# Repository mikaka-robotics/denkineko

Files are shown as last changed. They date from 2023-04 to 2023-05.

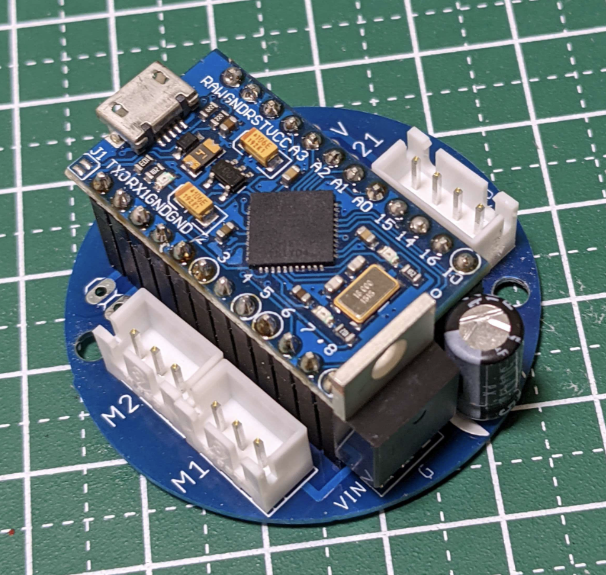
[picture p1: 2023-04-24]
circuit/circuit.png

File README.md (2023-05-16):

# 電気ネコ

- Demo動画<br>
demo (https://www.youtube.com/watch?v=TgMYkIjSbwk)

### デモの実行方法
事前に[こちらのNotebook](https://colab.research.google.com/drive/1hb-0-26DFwklIStM_WgTVe1c2eLKU9Zp?usp=sharing)でGradio web appを起動して、URL(https://XXXXXXXX.gradio.live/) をコピーしておく

```
git clone https://github.com/mikaka-robotics/denkineko.git
cd denkineko
(Macの場合) brew install portaudio
pip install -r  requirements.txt

python app.py --gradio_url https://XXXXXXXX.gradio.live/
```

起動後、[デモ動画](https://www.youtube.com/watch?v=TgMYkIjSbwk)のように頭のネジに触ることで会話を始められます。  

また、gradio_urlを与えずに`python app.py`のみで起動し、コマンドラインに直接コマンドを打ち込んでロボットを動かしてみることもできます。(送れるコマンドの詳細は以下)

# 開発者向け

スクリーンショット 2023-05-16 6 19 48

## ロボットとの通信方法の詳細
ロボットとの通信は、USBシリアル通信によって行っています。通信速度は9600bpsです。

- pythonなら以下のように命令を送れます. 

```python
import serial
import serial.tools.list_ports

com_ports = list(serial.tools.list_ports.comports())
#Arduinoが繋がっているportを調べて接続する
for port in com_ports:
    if "Arduino" in port.description:
        print("connect to " + port.device)     
        ser = serial.Serial(port.device, 9600, timeout=0.10)
        break

ser.write("nod,rainbow".encode())
```

ロボットが受け付ける命令は以下です。

|  コマンド名 | 動作 | 
| --- | --- |
| nod | うなずく nodnodで２回うなずく | 
| shake_body | 体を左右に揺らす | 
| neck数字 | 数字の角度に首を縦に動かす  例: neck80<br>範囲は (下向き  65 ~  90 上向き) | 
| body数字 | 数字の角度に体を横に動かす 例: body120<br>範囲は (右  0 ~  180 左) | 
| home | 首と体をホームポジションに戻す | 
| ready | LEDを通常状態にする | 
| rainbow | LEDを虹色にする | 
| lipsync | LEDをランダムに明滅させる | 
| sleep | スリープモードにする(ロボットが寝ます) | 
| blue | LEDを青にする | 
| yellow | LEDを黄色にする | 
| red | LEDを赤にする | 
| orange | LEDをオレンジにする | 
| white | LEDを白にする | 
| bright数字 | LEDの明るさを調整する (0~255)<br>例: bright50 | 
| status | 現在のロボットの状態を送信させる<br>[sleep/ready] | 

- 逆に、ロボット頭のネジがタッチされた場合は、`touch`という文字列がロボットから送られてきます。
- 命令はカンマ区切りで同時に複数送れます (ex `nod,rainbow`)

## ロボットのプログラムについて
- 使っているマイコンは[Arduino Leonardo](www.amazon.co.jp/dp/B07C31L2B6)です。  
  [こちら](https://github.com/mikaka-robotics/denkineko/blob/main/arduino_sketch/denkineko.ino)に書き込んでいるスケッチを置いています。

## 部品について
使用している主な部品は以下です。  

|  部品 | 数 | 型番など | 
| --- | --- | --- |
| サーボモータ | 2 | www.amazon.co.jp/dp/B09V4PZFCM  | 
| Arduino | 1 | www.amazon.co.jp/dp/B07C31L2B6 | 
| RGB LED | 1 | https://akizukidenshi.com/catalog/g/gI-08411/ | 
| 3.3V 3端子レギュレータ | 1 | https://akizukidenshi.com/catalog/g/gI-14505/| 

## 回路について
台座部分に回路が入っています。

スクリーンショット 2023-05-16 6 54 43

Eagleのプリント基板データがcircuitフォルダに入っています (部品名などめちゃくちゃ). 

スクリーンショット 2023-04-16 18 42 36. 




## 3Dプリントデータ
こちらのGoogle Driveにstlファイルがあります。  
https://drive.google.com/drive/folders/1kf-iSnG7YmpUBoflxnHEyxiMmFvtSxVS?usp=sharing. 
外装部分については光造形方式の3Dプリンタ必須です。

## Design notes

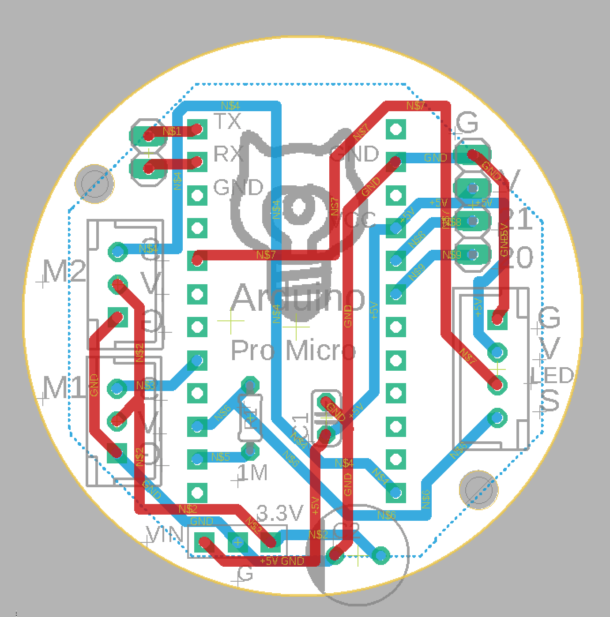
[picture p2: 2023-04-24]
circuit/board.png

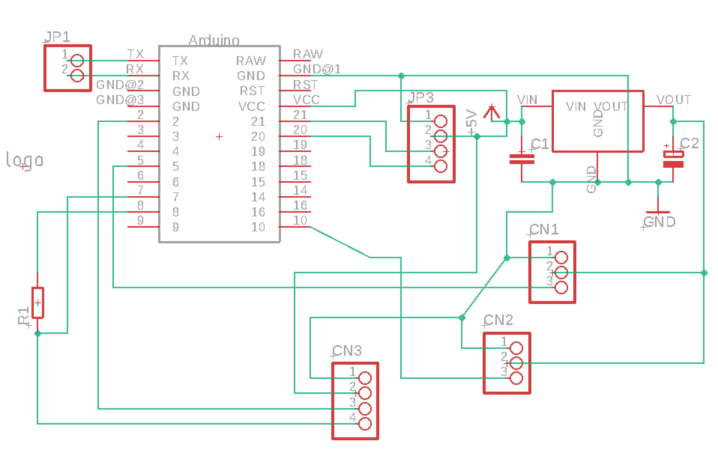
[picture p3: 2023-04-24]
circuit/sketch.png

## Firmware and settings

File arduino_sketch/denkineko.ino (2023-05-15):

#include <Adafruit_NeoPixel.h> //ライブラリの読み込み
#include <Adafruit_TiCoServo.h>
#include <MsTimer2.h>

#define LEDPIN 2
#define NUMLED 1
#define DELAY_TIME 100 //待ち時間1の設定

const int SENSOR_1_OUT = 8;
const int SENSOR_1_IN = 7;
const int threshold = 6;

int MOTER_PWN1 = 5;
int MOTER_PWN2 = 10;

float target_angle_neck = 90;
float current_angle_neck = 90;

float target_angle_body = 90;
float current_angle_body = 90;

Adafruit_TiCoServo myservo_neck;
Adafruit_TiCoServo myservo_body;

Adafruit_NeoPixel strip = Adafruit_NeoPixel(NUMLED, LEDPIN, NEO_RGB + NEO_KHZ800);
uint16_t led_max_value = 70;  // 輝度の設定をする(暗い←0 ～ 255→明い)
uint32_t base_color = strip.Color(0, 0, led_max_value); //LEDの色

uint16_t steps = 0;
String robot_status = "sleep";
String led_status = "";
String action = "";

bool is_autonomous=true;

unsigned long now;
unsigned long last_touched_time = 0; //チャタリング防止用
unsigned long last_interaction_time = 0; //自動sleep用
unsigned long action_start_time = 0; //動作生成用
int body_angle = 90; //体の向き (センター位置 記憶用)

void setup() {
  pinMode(SENSOR_1_OUT, OUTPUT);
  pinMode(SENSOR_1_IN, INPUT);
  Serial.begin(9600);
  delay(500);
  myservo_neck.attach(MOTER_PWN1, 500, 2400);
  myservo_neck.write(70);
  myservo_body.attach(MOTER_PWN2, 500, 2400);
  myservo_body.write(90);

  //LEDの設定
  strip.begin();   //インスタンスの使用を開始、この時全てのLEDの状態を「0」とする。
  strip.setBrightness(led_max_value);
  strip.show(); //Arduinoから全てのLEDへオフ信号「0」を転送し初期化する。

  //タイマー
  MsTimer2::set(10, timerISR);
  MsTimer2::start();

  last_interaction_time = millis();

  delay(500);
  Serial.println("ready");
}

uint32_t Wheel(byte WheelPos) {
  if(WheelPos < 85) {
   return strip.Color((WheelPos * 3)*led_max_value/255, (255 - WheelPos * 3)*led_max_value/255, 0);
  } else if(WheelPos < 170) {
   WheelPos -= 85;
   return strip.Color((255 - WheelPos * 3)*led_max_value/255, 0, (WheelPos * 3)*led_max_value/255);
  } else {
   WheelPos -= 170;
   return strip.Color(0, (WheelPos * 3)*led_max_value/255, (255 - WheelPos * 3)*led_max_value/255);
  }
}

// LEDを連続的に変化させる関数
void controlLED() {
  steps=steps+1; //0~255をインクリメントするだけの変数
  if(steps>255){steps=0;}

  if(robot_status == "sleep"){
    int k=steps;
    if(k>125){k=256-k;} //ゆっくり明滅
      strip.setPixelColor(0, strip.Color(k*led_max_value/256,k*led_max_value/256,k*led_max_value/256));
      strip.show();
  }else if(led_status == "rainbow"){
      strip.setPixelColor(0, Wheel((steps) & 255));
      strip.show();
  }else if(led_status == "lipsync"){
    if(steps%5==0){
        int randNum = random(30); //ランダムに明滅させる
        if (randNum < 15) {
            strip.setPixelColor(0, base_color);
        } else {
          strip.setPixelColor(0,strip.Color(0,0,0));
        }
        strip.show();
    }
  }else if(led_status == "touch"){
      strip.setPixelColor(0, strip.Color(led_max_value, 0, 0)); //RED
      strip.show();
  }else if(led_status == "off"){
      strip.setPixelColor(0, strip.Color(0, 0, 0));
      strip.show();
  }else if(strip.getPixelColor(0) != base_color){
      strip.setPixelColor(0, base_color);
      strip.show();
  }
}

void timerISR() {
  now = millis();
  controlLED();

  if(robot_status == "sleep"){
    target_angle_neck = 70+8*sin(now/600.); //sin関数で首を上下に動かす
  }

  if(action == "nod" & (now-action_start_time)<2*PI*200){
    target_angle_neck = 70 - 8*sin((now-action_start_time)/200.+PI/4.); //うなずく sin関数で首を上下に動かす
  }
  if(action == "nodnod" & (now-action_start_time)<2*PI*400){
    target_angle_neck = 70 - 8*sin((now-action_start_time)/200.+PI/4.); //2回 うなずく
  }
  if(action == "shake_body" & (now-action_start_time)<2*PI*200){
    target_angle_body = body_angle - 12*sin((now-action_start_time)/200); //sin関数で体を左右に振らす
  }
  if(is_autonomous & action == "awake" & (now-action_start_time)<2*PI*200){
    target_angle_neck = 55;
    target_angle_body = body_angle - 20*sin((now-action_start_time)/200); //sin関数で体を左右に振らす
  }


  int diff = (target_angle_neck - current_angle_neck); //操作量
  diff = constrain(diff, -1, 1); //一度の操作量を制限する
  current_angle_neck = current_angle_neck + diff; //操作量を加える
  current_angle_neck = constrain(current_angle_neck, 55, 80);
  myservo_neck.write((int)current_angle_neck);

  diff = (target_angle_body-current_angle_body);
  diff = constrain(diff, -1, 1);
  current_angle_body = current_angle_body + diff;
  current_angle_body = constrain(current_angle_body, 10, 170);
  myservo_body.write((int)current_angle_body);

  //静電容量によるタッチ判定
  int counter=0;
  digitalWrite(SENSOR_1_OUT, HIGH);
  while (digitalRead(SENSOR_1_IN)!=HIGH) counter++;
  digitalWrite(SENSOR_1_OUT, LOW);

  if (counter > threshold) { //タッチされた
    led_status = "touch";
    if (now - last_touched_time > 300){ //チャタリング防止
        Serial.println("touch");
        robot_status = "ready";
        action_start_time = millis();
        action = "awake";
    }
    strip.show();
    last_touched_time = now;
    last_interaction_time = now;
  }

  if(now - last_touched_time > 300 & led_status=="touch"){
    led_status = "";
  }

  if(((now - last_interaction_time)/1000 > 2*60) & (now - last_touched_time > 10*1000)){ //最後にインタラクションしてから2分たったらsleepモード
    robot_status = "sleep";
    is_autonomous = true;
    if((now - last_interaction_time)/1000 > 60*60){ //さらに、最後にインタラクションしてから60分たっていたら停止させる
      robot_status = "ready";
      led_status = "";
    }
  }
}

void loop() {
  if (Serial.available() > 0) {
    String received_data = Serial.readStringUntil('\n'); // 改行文字が来るまでの文字列を読み込む
    parseCommands(received_data);
    last_interaction_time = millis();
  }

}

//カンマ区切りになっているデータをパースする
void parseCommands(String input) {
  int startIndex = 0;
  while (startIndex < input.length()) {
    int endIndex = input.indexOf(',', startIndex);
    if (endIndex == -1) {
      endIndex = input.length();
    }

    String command = input.substring(startIndex, endIndex);
    command.trim();
    processCommand(command);
    startIndex = endIndex + 1;
  }
}

int getSeparatorIndex(String command){
  int separatorIndex = -1;
  for (int i = 0; i < command.length(); i++) {
    if (command.charAt(i) >= '0' && command.charAt(i) <= '9') {
      separatorIndex = i;
      break;
    }
  }

  if (separatorIndex == -1) {
    return command.length();
  }
  return separatorIndex;
}

bool isNumeric(String str) {
  for (int i = 0; i < str.length(); i++) {
    if (!isDigit(str.charAt(i))) {
      return false;
    }
  }
  return true;
}

void processCommand(String command) {
  int separatorIndex = getSeparatorIndex(command);
  String key = command.substring(0, separatorIndex);
  String valueString = command.substring(separatorIndex);
  int value = 0;
  if (isNumeric(valueString)) {
    value = valueString.toInt();
  }

  is_autonomous=false; //自律モード解除

  if(key=="rainbow"){
    robot_status = "ready";
    led_status = "rainbow";
  }else if(key=="sleep"){
    robot_status = "sleep";
    is_autonomous=true;
    led_status = "";
  }else if(key=="lipsync"){
    robot_status = "ready";
    led_status = "lipsync";
  }else if(key=="ready"){
    led_status = "";
    robot_status = "ready";
  }else if(key=="home"){
    robot_status = "ready";
    target_angle_neck=70;
    target_angle_body=90;
    body_angle = 90;
  }else if(key=="blue"){
    base_color = strip.Color(0, 0, led_max_value);
  }else if(key=="yellow"){
    base_color = strip.Color(led_max_value, led_max_value*0.8, 0);
  }else if(key=="red"){
    base_color = strip.Color(led_max_value*0.8, 0, 0);
  }else if(key=="orange"){
    base_color = strip.Color(led_max_value*0.8, led_max_value*0.3, 0);
  }else if(key=="white"){
    base_color = strip.Color(10, 10, 10);
  }else if(key=="bright"){
    led_max_value = value;
    strip.setBrightness(value); //輝度はsetPixelColorにセットした値よりもこっちの方が優先されるよう
    strip.show();
  }else if(key=="neck"){
    robot_status = "ready";
    target_angle_neck=value;
  }else if(key=="body"){
    robot_status = "ready";
    target_angle_body = value;
    body_angle = value;
  }else if(key=="nod"){ //うなずく
    robot_status = "ready";
    action_start_time = millis();
    action = "nod";
  }else if(key=="nodnod"){ //2回うなずく
    robot_status = "ready";
    action_start_time = millis();
    action = "nodnod";
  }else if(key=="shake_body"){ //体を２回左右に揺らす
    robot_status = "ready";
    action_start_time = millis();
    action = "shake_body";
  }else if(key=="status"){
    Serial.println(robot_status);
  }else if(key=="autonomous"){
    is_autonomous=true;
  }else{
    Serial.println("error");
  }
}

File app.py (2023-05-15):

from gradio_client import Client
import base64
import argparse
import json
import webrtcvad
import os
import pyaudio
import wave
import time
import threading
from threading import Lock
import serial
import ctypes
import simpleaudio as sa
import serial.tools.list_ports

# 引数の解析を定義する
parser = argparse.ArgumentParser(
    description='Denki Neko Controller', add_help=True)
parser.add_argument(
    '--gradio_url', help='gradio demo url (like https://xxxxxxxx.gradio.live/)')
args = parser.parse_args()
gradio_url = args.gradio_url


class Robot():
    _instance = None
    _lock = Lock()

    def __new__(cls, gradio_url=None):
        # シングルトン
        with cls._lock:
            if cls._instance is None:
                cls._instance = super().__new__(cls)
                cls._instance.serial = None  # シリアル通信のコネクター
                cls._instance.background_read_thread = None
                cls._instance.is_on_switch = False
                cls._instance.is_stop = False
                cls._instance.history = []
                cls._instance.play_obj = None
                cls._instance.is_recording = False
                cls._instance.status = 'ready'
                cls._instance.action = ''
                cls._instance.cureent_th_id = 0
                cls._instance.gradio_url = gradio_url
                if cls._instance.gradio_url is not None:
                    cls._instance.client = Client(cls._instance.gradio_url)
                cls._instance.vad = webrtcvad.Vad(mode=3)

        return cls._instance

    def init(self):
        self.connect()
        self.stop()
        self.history = []
        robot.status = 'sleep'

    def connect(self):
        # シルアルポートに接続する
        if self.serial:
            return True

        com_ports = list(serial.tools.list_ports.comports())
        for port in com_ports:
            if "USB Serial Device" in port.description or "Arduino" in port.description:
                print("connect to " + port.device)
                try:
                    self.serial = serial.Serial(
                        port.device, 9600, timeout=0.10)
                    return True
                except:
                    self.serial = None
                    return False

        for device in os.listdir('/dev'):
            if "tty.usb" in device or "ttyUSB" in device:  # raspiの場合は ttyUSB
                print("connect to " + device)
                try:
                    self.serial = serial.Serial(
                        "/dev/" + device, 9600, timeout=0.10)
                    return True
                except:
                    self.serial = None
                    return False
        return False

    def send_msg(self, msg):
        msg = msg + '\n'
        print("send:" + msg)
        self.serial.write(msg.encode())

    def make_talk_thread(self):
        self.stop()
        time.sleep(0.1)
        self.cureent_th_id += 1
        self.background_read_thread = threading.Thread(name='talk_thread',
                                                       target=self.talk_thread, args=(self.cureent_th_id,))
        self.background_read_thread .setDaemon(True)
        self.background_read_thread .start()
        return

    def stop(self):
        self.status = 'ready'
        self.recording = False
        if self.play_obj is not None:
            self.play_obj.stop()
        for thread_id, thread in threading._active.items():
            if 'talk_thread' in thread.name:
                res = ctypes.pythonapi.PyThreadState_SetAsyncExc(
                    ctypes.c_long(thread_id), ctypes.py_object(SystemExit))
        return

    def is_playing(self):
        if self.play_obj is None:
            return False
        return self.play_obj.is_playing()

    def record(self):
        # PyAudioの設定
        FORMAT = pyaudio.paInt16
        CHANNELS = 1
        RATE = 48000
        CHUNK_DURATION_MS = 30
        PADDING_DURATION_MS = 1500
        CHUNK_SIZE = int(RATE * CHUNK_DURATION_MS / 1000)
        PADDING_SIZE = int(RATE * PADDING_DURATION_MS / 1000)
        START_OFFSET = int(PADDING_SIZE / CHUNK_SIZE)

        audio = pyaudio.PyAudio()
        stream = audio.open(format=FORMAT, channels=CHANNELS,
                            rate=RATE, input=True, frames_per_buffer=CHUNK_SIZE)

        # 録音中のフラグ
        recording = False

        # 録音した音声を格納するリスト
        frames = []
        active_flag = []

        # PyAudioストリームの開始
        stream.start_stream()

        start_time = time.time()

        while 1:
            frame = stream.read(CHUNK_SIZE)
            active = self.vad.is_speech(frame, RATE)
            active_flag.append(active)

            if len(active_flag) > 20:
                active_flag.pop(0)

            frames.append(frame)

            if not recording and sum(active_flag) > 10:
                print('Recording started...')
                self.status = 'recording'
                recording = True
            if not recording and len(frames) > 30:
                frames.pop(0)
            if recording and sum(active_flag) == 0:
                print('Recording stopped...')
                break

            if (time.time() - start_time > 10) and not recording:  # timeout
                break

        if not recording:
            return None

        stream.stop_stream()
        stream.close()
        audio.terminate()

        # 録音された音声を保存する
        wavefile = wave.open('recording.wav', 'wb')
        wavefile.setnchannels(CHANNELS)
        wavefile.setsampwidth(audio.get_sample_size(FORMAT))
        wavefile.setframerate(RATE)
        wavefile.writeframes(b''.join(frames))
        wavefile.close()
        return 'recording.wav'

    def gradio_api_call(self, send_wav_file):
        chat_history_text = json.dumps(self.history, ensure_ascii=False)

        result = self.client.predict(
            send_wav_file,
            chat_history_text,
            api_name="/myChatGPT"
        )

        recognized_text = result[1]
        print(recognized_text)

        response_text = result[2]
        print(response_text)

        chat_history_text = result[3]
        self.history = self.parse_chat_history_text(chat_history_text)

        self.action = result[4]

        received_audio_data = result[5]
        decoded_audio = base64.b64decode(received_audio_data)

        output_filename = "output.wav"

        # デコードされたデータをファイルに書き込む
        with open(output_filename, "wb") as f:
            f.write(decoded_audio)

        return output_filename

    def talk_thread(self, th_id):
        self.status = 'waiting'
        input_sound_filename = self.record()

        if th_id != self.cureent_th_id:  # 録音中に別の応答が始まっていて場合中断
            return

        if input_sound_filename is None:
            self.status = 'ready'
            return
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

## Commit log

2023-04-26 windowsに対応
2023-05-15 arudino sketch更新
2023-05-15 serial接続方法変更
2023-05-15 stlはgoogle driveに移動
    [base_rod.stl, base_sabo1.stl, base_sabo2.stl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]
2023-05-16 requirements追加
